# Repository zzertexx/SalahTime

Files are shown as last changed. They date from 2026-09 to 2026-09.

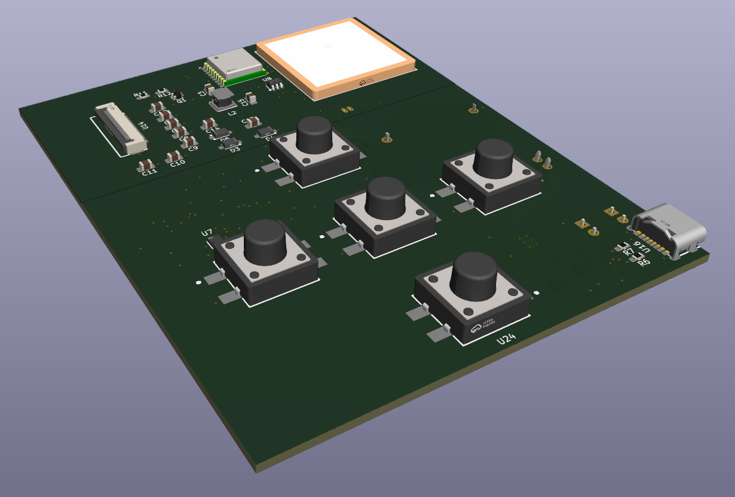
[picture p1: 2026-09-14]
Images/PCB_Front.png

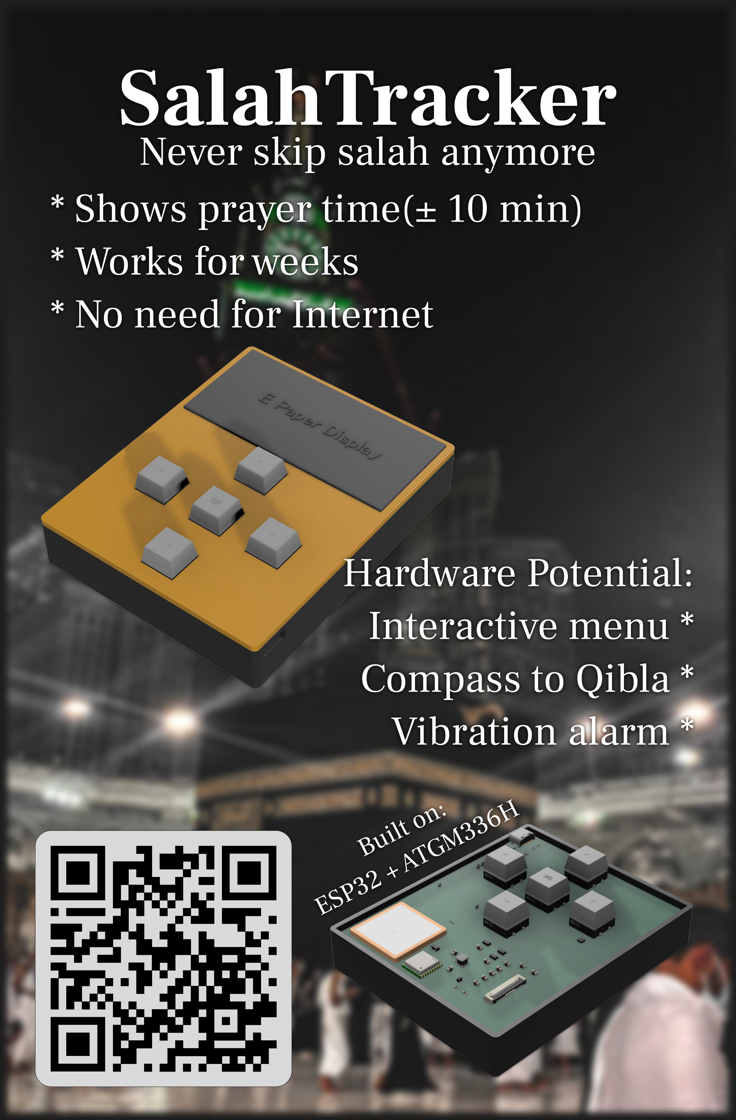
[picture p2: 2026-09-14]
Zine.png

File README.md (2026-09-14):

# SalahTime
Device that shows prayer time and Qibla direction anywhere & anytime without any internet connection
Zine

## What is it?
It is an ESP32-powered device with buttons, GNSS receiver, RTC, magnetic sensor, and E-Paper display. By using all of these, it is planned to show prayer time using latitude and longitude alongside with direction to Qibla by magnetic sensor. Because there is an E-Paper display, battery can last for many-many days. If the battery will be drained, it is easy to charge using universal Type-C port. Currently, it shows prayer time based on location, but will have full interface and direction to Qibla in the future.

## Why did I build it?
I was walking in Shenzhen after Fallout with my phone died and then realized that I have to read Salah
I could not know if the next salah already started and I needed the direction to Qibla
Strangers there do not understand English, so I could not communicate with them
Then, I got an idea of internet-free device that can predict prayer time and show the direction to Qibla

## Steps to Reproduce
1. Order PCB and parts from any provider(Example: JLCPCB)
2. Assemble and solder parts to PCB
3. 3D Print CAD models from "CAD" folder
4. Push software into MCU and download required libraries using Arduino IDE 
5. Use!

## Arduino IDE Libraries:
GxEPD2
TinyGPS++
RTClib

## Bill of Materials
| Name | Quantity | Price |
| --- | --- | --- |
| DS3231M RTC | 1 | 3.25$ |
| ATGM336H GNSS | 1 | 2.22$ |
| ESP32-C3FH4 | 1 | 2.18$ |
| Vibration Motor | 1 | 0.56$ |
| Tactile Push Buttons | 5 | 0.3$ |
| Ceramic Active Antenna | 1 | 0.73$ |
| Coin Cell Holder | 1 | 1.27$ |
| MAX17048 fuel gauges | 1 | 2.18$ |
| ME6211 LDO to 3.3v | 1 | 0.52$ |
| NPN Transistor | 1 | 0.02$ |
| 2.9-inch E Ink Display | 1 | 4$ |
| 803040 1000 mAh LiPo | 1 | 4$ |
| Type-C 8 Pin | 1 | 0.04$ |
| 2.5mm JST Connector | 1 | 0.04$ |
| SI1308EDL N-MOSFET | 1 | 0.1$ |
| TP4056 | 1 | 0.2$ |
| FS8205A | 1 | 0.05$ |
| DW01A | 1 | 0.5$ |
| E Ink connector | 1 | 0.11$ |
| QST QMC5883P | 1 | 1.6$ | 
| 0,1uF C | 6 | 0.2$ |
| 10uF | 3 | 0.2$ | 
| 1uF/25V | 14 | 0.7$ |
| 4.7uF/25V | 3 | 0.2$ |
| 15pF | 2 | 0.03$ |
| 10nF | 1 | 0.02$ |
| THT 3mm diodes | 2 | 0.07$ |
| MBR0530 Diode | 3 | 0.02$ |
| 47nH L | 1 | 0,06$ |
| 47uH L | 1 | 0.08$ |
| 2nH L | 1 | 0.01$ |
| 10K R | 1 | 0.01$ |
| 1K R | 4 | 0.01$ |
| 1.2K R | 1 | 0.05$ |
| 4.7K R | 2 | 0.07$ |
| 100 R | 1 | 0.01$ |
| 1M R | 1 | 0.01$ |
| 2.2 R | 1 | 0.01$ |
| 499 R | 1 | 0.01$ |
| 0 R | 1 | 0.01$ |
| 10pF Crystal | 1 | 0.3$ | 
| TOTAL: | 26$ |

## Images
salah_tracker
salah_tracker2
[schematics.pdf](https://github.com/user-attachments/files/32201017/schematics.pdf)
PCB_Front
PCB_Behind

## AI DISCLOSURE
AI was used to search components and to write computing algorithm

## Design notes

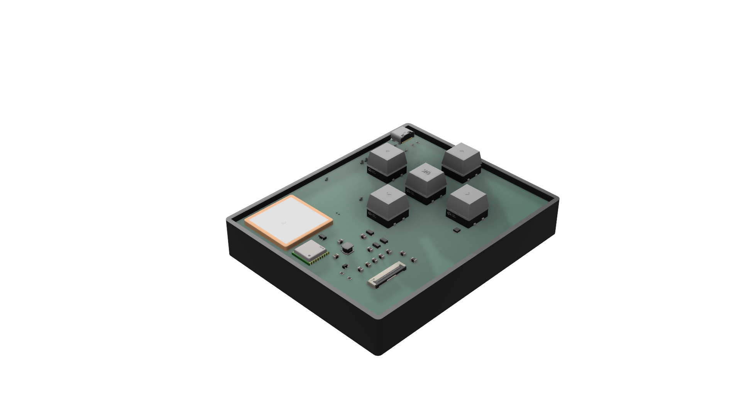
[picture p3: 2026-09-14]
Images/salah_tracker2.png

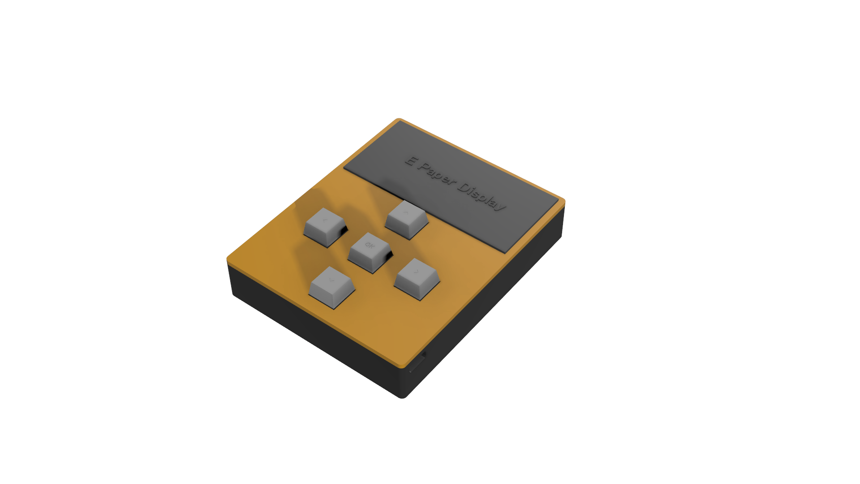
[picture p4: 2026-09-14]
Images/salah_tracker.png

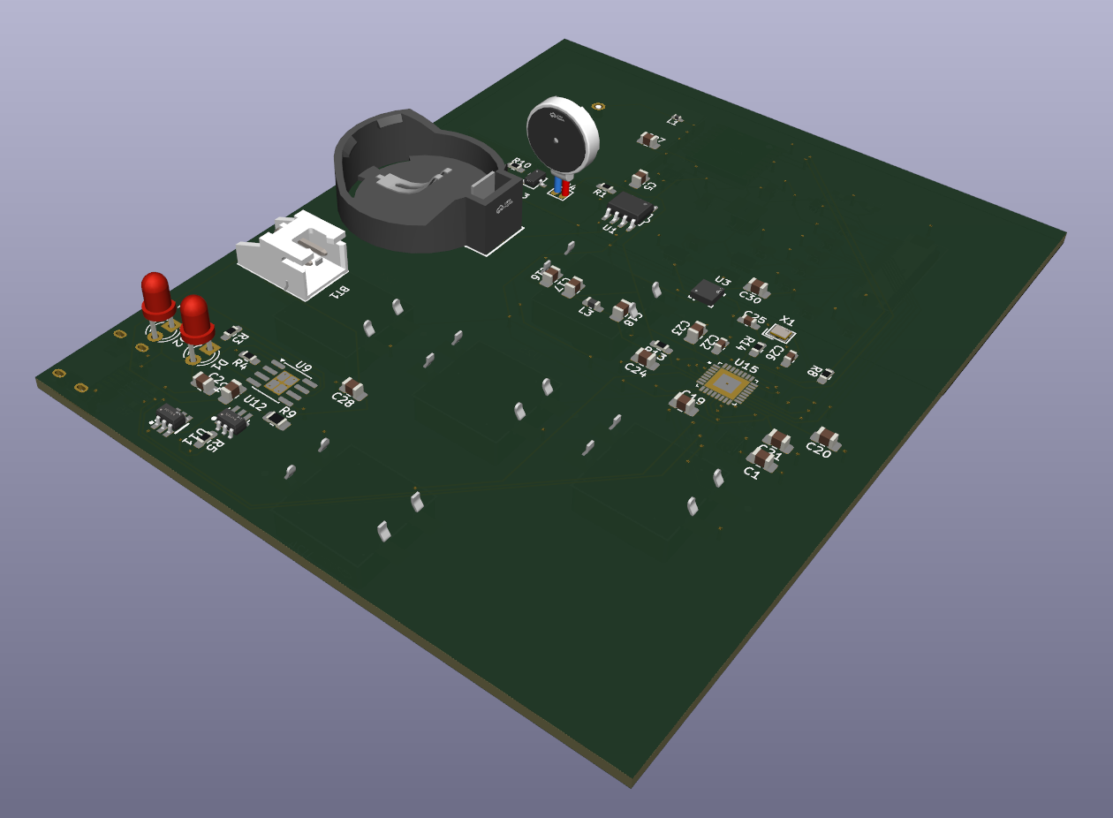
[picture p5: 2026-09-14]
Images/PCB_Behind.png

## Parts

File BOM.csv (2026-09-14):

Name | Quantity | Total Price | LCSC Number | Link
MAXIM DS3231MZ+TRL | 1 | $3,25 | C107410 | https://www.lcsc.com/product-detail/C107410.html?s_z=n_q_%2509DS3231MZ%2520TRL
ZHONGKEWEI ATGM336H-7N76 | 1 | $2,22 | C53325902 | https://www.lcsc.com/product-detail/C53325902.html
ESP32-C3FH4 | 1 | $2,18 | C2858491 | https://www.lcsc.com/product-detail/C2858491.html
Vibration Motor | 1 | $0,56 | C2759984 | https://jlcpcb.com/partdetail/LEADER-LCM1027A2445F/C2759984
Push Switch | 5 | $0,30 | C48677734 | https://www.lcsc.com/product-detail/C48677734.html?s_z=n_q_C48677734&globalKeyword=C48677734
Ceramic Active Antenna | 1 | $0,73 | C784398 | https://www.lcsc.com/product-detail/C784398.html
Coin Cell Holder | 1 | $1,27 | C964745 | https://www.lcsc.com/product-detail/C964745.html
MAX17048 | 1 | $2,18 | C2682616 | https://www.lcsc.com/product-detail/C2682616.html?s_z=n_q_MAX17048%2520
ME6211 | 1 | $0,52 | C82942 | https://www.lcsc.com/product-detail/C82942.html?s_z=n_q_t_ME6211%2520
NPN Transistor | 1 | $0,02 | C52801 | https://www.lcsc.com/product-detail/C52801.html?s_z=n_q_t_NPN%2520
2.9-inch E Ink Display | 1 | $4,00 |  | https://www.alibaba.com/product-detail/2-9inch-2-9-E-Ink_1601697951336.html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
803040 1000 mAh LiPo | 1 | $4,00 |  | https://aliexpress.ru/item/1005008542711399.html?sku_id=12000045637966057
Type-C 8 Pin | 1 | $0,04 | C47326496 | https://www.lcsc.com/product-detail/C47326496.html
2.5mm JST Connector | 1 | $0,04 | C158012 | https://www.lcsc.com/product-detail/C158012.html?s_z=n_q_t_2.5%2520mm%25202%2520pin
SI1308EDL | 1 | $0,10 | C7603347 | https://www.lcsc.com/product-detail/C7603347.html?s_z=n_q_Si1308EDL
TP4056 | 1 | $0,20 | C16581 | https://www.lcsc.com/product-detail/C16581.html?s_z=n_q_TP4056
FS8205A | 1 | $0,05 | C2830320 | https://www.lcsc.com/product-detail/C2830320.html?s_z=s_p_FS8205A
DW01A | 1 | $0,50 | C351410 | https://www.lcsc.com/product-detail/C351410.html?s_z=n_q_DW01A
BC817-40,215 | 1 | $0,01 | C52801 | https://www.lcsc.com/product-detail/C52801.html?s_z=n_q_C52801&globalKeyword=C52801
E Ink connector | 1 | $0,11 | C2856805 | https://www.lcsc.com/product-detail/C2856805.html?s_z=n_q_C2856805&globalKeyword=C2856805
QST QMC5883P | 1 | $1,57 | C2847467 | https://www.lcsc.com/product-detail/C2847467.html
Capacitors:
0,1uF | 6 | $0,20 | C49678 | https://www.lcsc.com/product-detail/C49678.html?s_z=n_q_t_capacitor
10uF | 3 | $0,20 | C15850 | https://www.lcsc.com/product-detail/C15850.html?s_z=n_q_t_capacitor
1uF/25V | 14 | $0,70 | C116352 | https://www.lcsc.com/product-detail/C116352.html?s_z=n_q_t_capacitor
4.7uF/25V | 3 | $0,20 | C98195 | https://www.lcsc.com/product-detail/C98195.html?s_z=n_q_t_capacitor
15pF | 2 | $0,03 | C1644 | https://www.lcsc.com/product-detail/C1644.html
10nF | 1 | $0,02 | C100042 | https://www.lcsc.com/product-detail/C100042.html
Diodes:
THT Red LED Diode 3mm | 2 | $0,07 | C99772 | https://www.lcsc.com/product-detail/C99772.html
MBR0530 | 3 | $0,02 | C5204746 | https://www.lcsc.com/product-detail/C5204746.html?s_z=n_q_MBR0530
Inductors:
47nH | 1 | $0,06 | C54534559 | https://www.lcsc.com/product-detail/C54534559.html?s_z=n_q_t_Inductor
47uH | 1 | $0,08 | C167888 | https://www.lcsc.com/product-detail/C167888.html?s_z=n_q_NR3015
2nH | 1 | $0,00 | C55067196 | https://www.lcsc.com/product-detail/C55067196.html?s_z=s_c_Fixed%2520Inductors
Resistors:
10K Pull Up | 1 | $0,01 | C98220 | https://www.lcsc.com/product-detail/C98220.html
1K | 4 | $0,01 | C2907002 | https://www.lcsc.com/product-detail/C2907002.html
1.2K | 1 | $0,05 | C2907002 | https://www.lcsc.com/product-detail/C269531.html
4.7K | 2 | $0,07 | C2904521 | https://www.lcsc.com/product-detail/C2904521.html
100 | 1 | $0,01 | C2907218 | https://www.lcsc.com/product-detail/C2907218.html
1M | 1 | $0,01 | C2907003 | https://www.lcsc.com/product-detail/C2907003.html
2.2 | 1 | $0,01 | C22939 | https://www.lcsc.com/product-detail/C22939.html
499 | 1 | $0,00 | C23065 | https://www.lcsc.com/product-detail/C23065.html
0 | 1 | $0,00 | C95177 | https://www.lcsc.com/product-detail/C95177.html
Crystal | 1 | $0,30 | C255898 | https://www.lcsc.com/product-detail/C255898.html

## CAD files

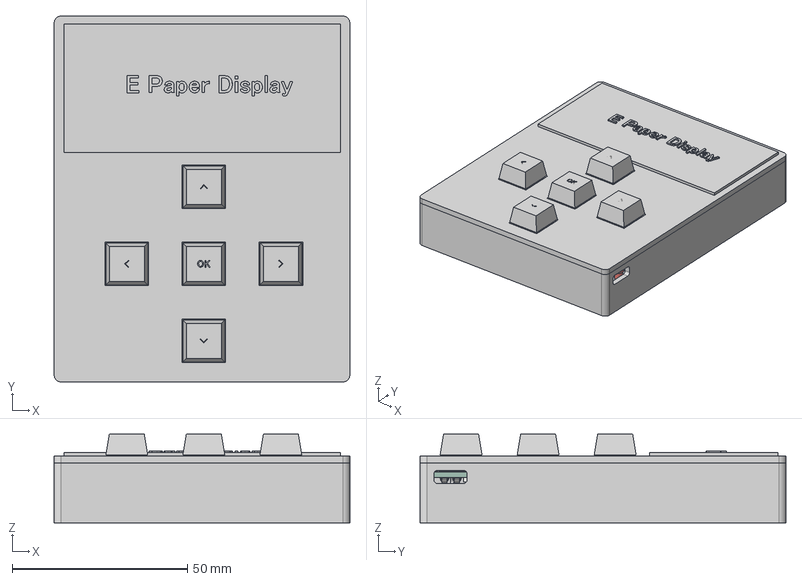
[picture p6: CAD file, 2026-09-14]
CAD/case.step
84.5 x 104.5 x 25.3 mm
cap for 12x12 (1)

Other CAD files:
CAD/case.f3z

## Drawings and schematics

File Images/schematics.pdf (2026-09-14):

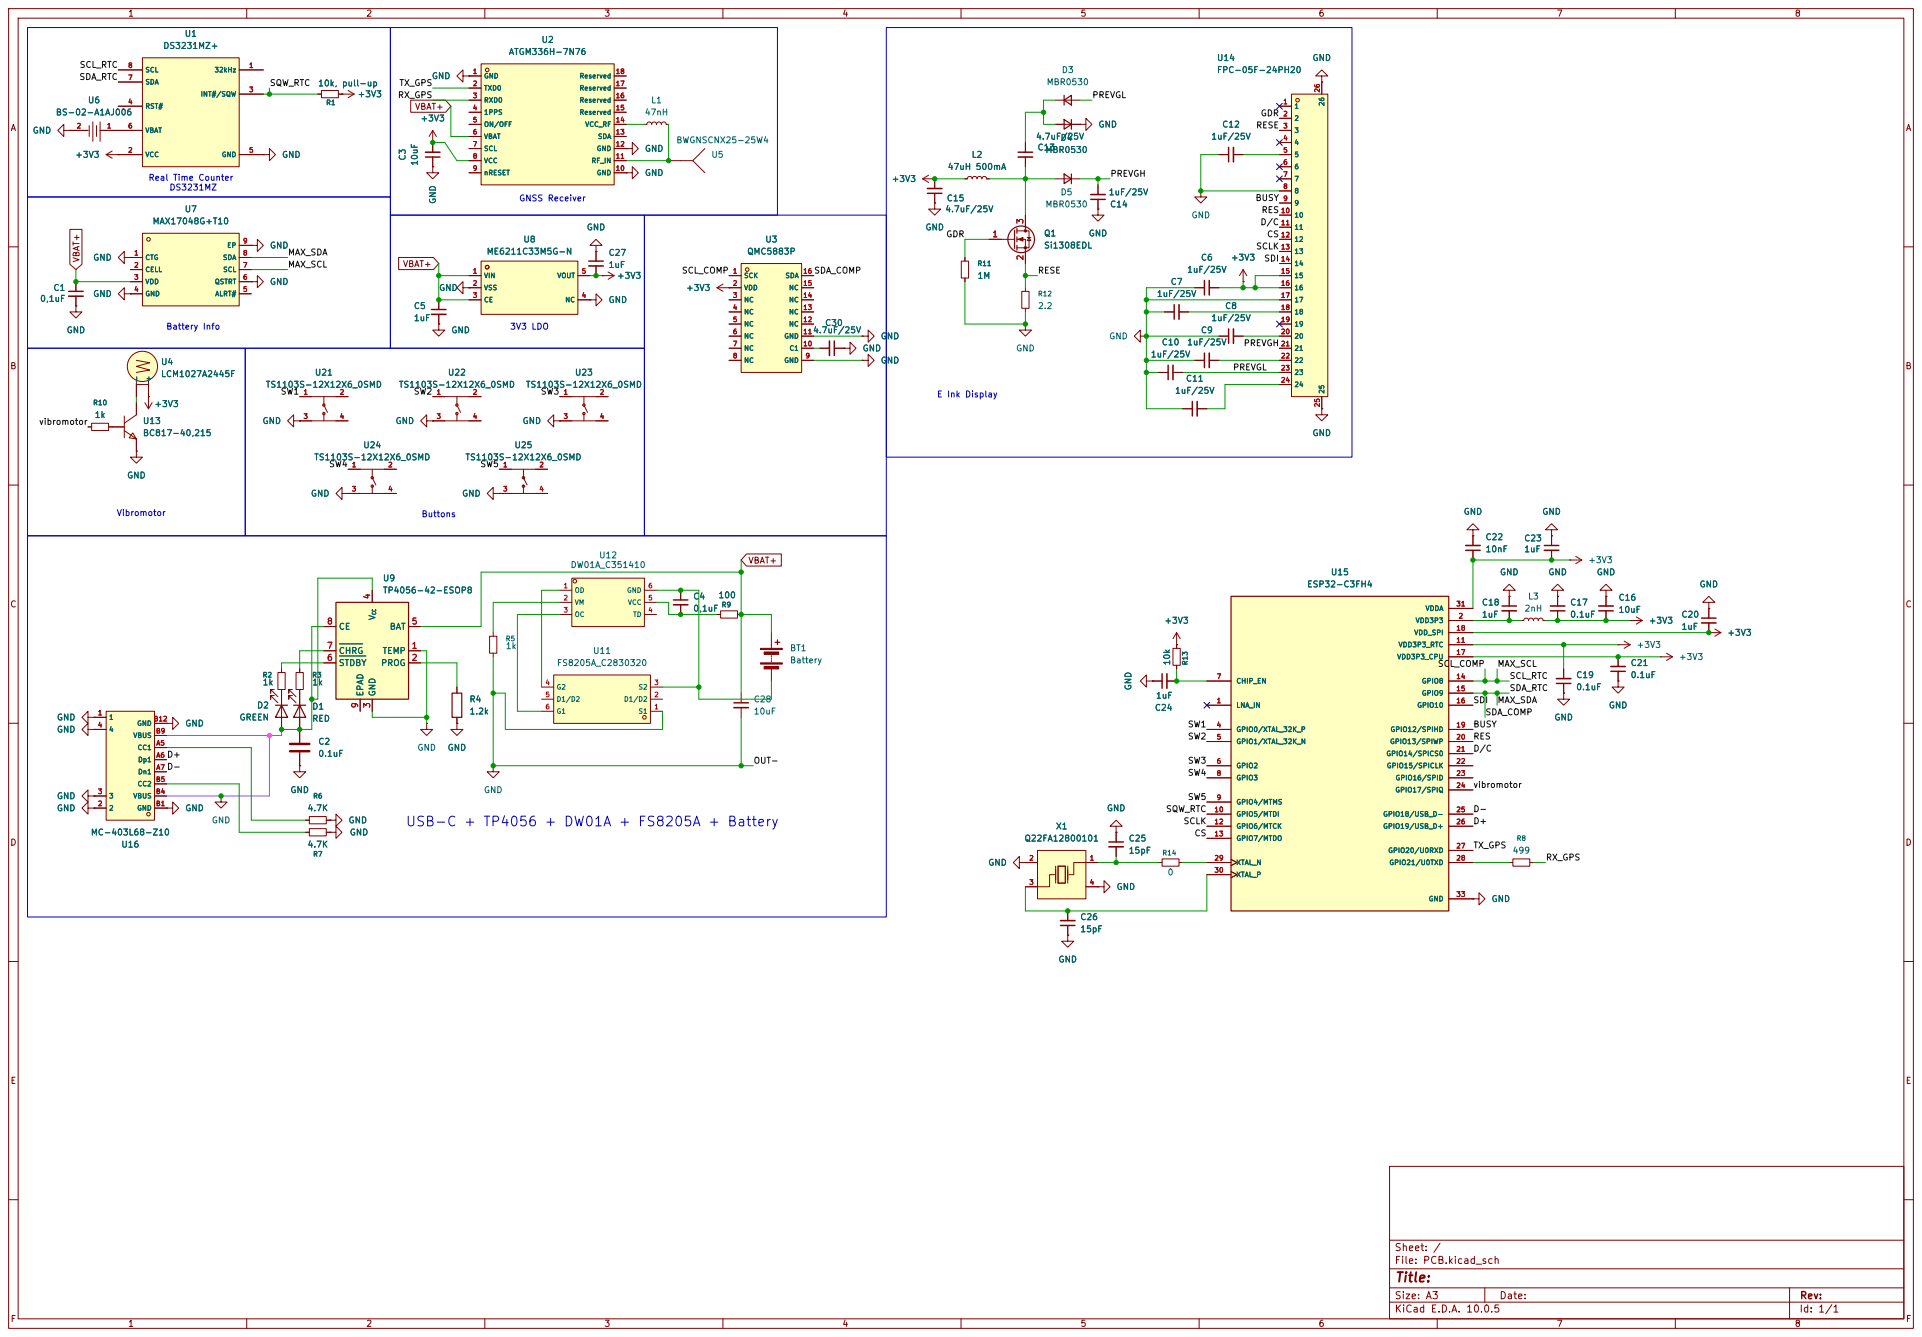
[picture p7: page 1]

GND | SDA | 16 U3 QMC5883P GND

VibromotorBattery Info LCM1027A2445F +3V3 LCM1027A2445F - | 3 4 U21 3 4 U21 3 4 U22 3 4 GND 3 U23 4 U23 TS1103S-12X12X6_0SMD TS1103S-12X12X6_0SMD TS1103S-12X12X6_0SMD TS1103S-12X12X6_0SMD TS1103S-12X12X6_0SMD TS1103S-12X12X6_0SMD 1 1 2 2 1 1 2 2 SW3 1 1 2 2 GND 3 4 GND U25 3 4 GND 3 4 U24 3 4 U25 TS1103S-12X12X6_0SMD TS1103S-12X12X6_0SMD TS1103S-12X12X6_0SMD TS1103S-12X12X6_0SMD SW4 1 1 2 2 SW5 1 1 2 2

Size: A3 | Rev: | F Date:
KiCad E.D.A. 10.0.5 | Id: 1/1

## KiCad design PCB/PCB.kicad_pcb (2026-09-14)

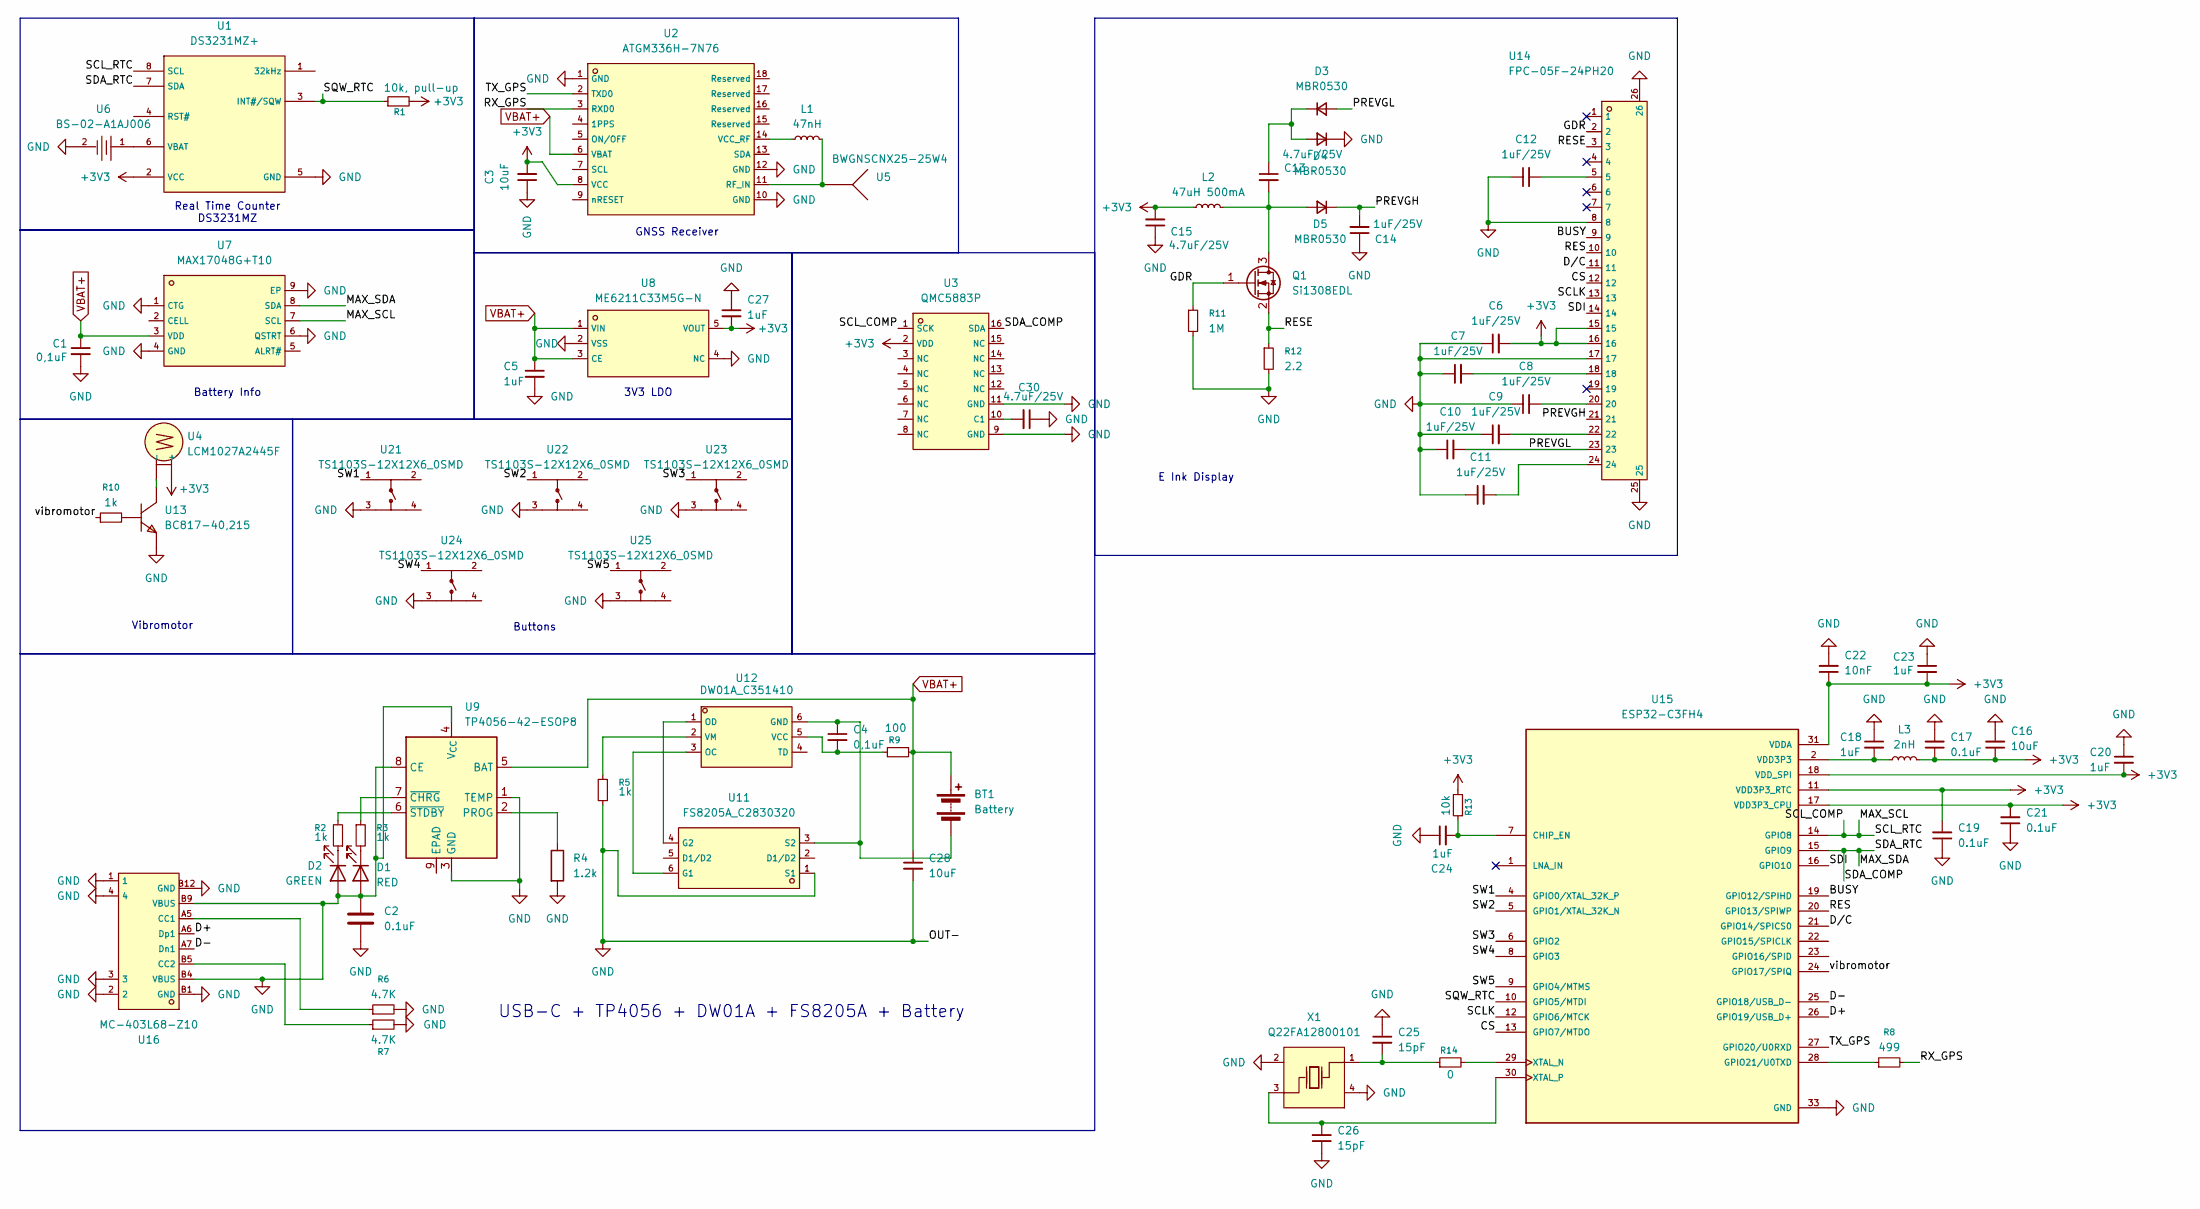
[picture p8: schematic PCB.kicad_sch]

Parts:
BT1: Battery; CONN-TH_S2B-XH-A-LF-SN
C1, C4: 0,1uF; C_0805_2012Metric_Pad1.18x1.45mm_HandSolder
C2, C17, C19, C21: 0.1uF; C_0805_2012Metric_Pad1.18x1.45mm_HandSolder
C3, C16, C28: 10uF; C_0805_2012Metric_Pad1.18x1.45mm_HandSolder
C5, C18, C20, C23, C24, C27: 1uF; C_0805_2012Metric_Pad1.18x1.45mm_HandSolder
C6, C7, C8, C9, C10, C11, C12, C14: 1uF/25V; C_0805_2012Metric_Pad1.18x1.45mm_HandSolder
C13, C15, C30: 4.7uF/25V; C_0805_2012Metric_Pad1.18x1.45mm_HandSolder
C22: 10nF; C_0603_1608Metric_Pad1.08x0.95mm_HandSolder
C25, C26: 15pF; C_0603_1608Metric_Pad1.08x0.95mm_HandSolder
D1: RED; LED_D3.0mm
D2: GREEN; LED_D3.0mm
D3, D4, D5: MBR0530; SOD-123_L2.7-W1.6-LS3.7-RD-1
L1: 47nH; L_0402_1005Metric_Pad0.77x0.64mm_HandSolder
L2: 47uH 500mA; IND-SMD_L4.0-W4.0_FNR40XXS
L3: 2nH; L_0603_1608Metric_Pad1.05x0.95mm_HandSolder
Q1: Si1308EDL; SOT-323_SC-70
R1: 10k, pull-up; R_0603_1608Metric_Pad0.98x0.95mm_HandSolder
R2, R3, R5, R10: 1k; R_0603_1608Metric_Pad0.98x0.95mm_HandSolder
R4: 1.2k; R_0603_1608Metric_Pad0.98x0.95mm_HandSolder
R6, R7: 4.7K; R_0603_1608Metric_Pad0.98x0.95mm_HandSolder
R8: 499; R_0603_1608Metric_Pad0.98x0.95mm_HandSolder
R9: 100; R_0805_2012Metric_Pad1.20x1.40mm_HandSolder
R11: 1M; R_0603_1608Metric_Pad0.98x0.95mm_HandSolder
R12: 2.2; R_0603_1608Metric_Pad0.98x0.95mm_HandSolder
R13: 10k; R_0603_1608Metric_Pad0.98x0.95mm_HandSolder
R14: 0; R_0603_1608Metric_Pad0.98x0.95mm_HandSolder
U1: DS3231MZ+; SOIC-8_L4.9-W3.9-P1.27-LS6.0-BL; LCSC C107410
U2: ATGM336H-7N76; COMM-SMD_18P-L10.1-W9.7-P1.1-TL_L76-LB; LCSC C53325902
U3: QMC5883P; LGA-16_L3.0-W3.0-P0.50-BL_SQ; LCSC C2847467
U4: LCM1027A2445F; VIBRATING-MOTOR-SMD_WELDING; LCSC C2759984
U5: BWGNSCNX25-25W4; ANT-TH_L25.0-W25.0; LCSC C784398
U6: BS-02-A1AJ006; BAT-TH_MYOUNG_BS-02-A1AJ006; LCSC C964745
U7: MAX17048G+T10; TDFN-8_L2.0-W2.0-P0.50-BL-EP1.2; LCSC C2682616
U8: ME6211C33M5G-N; SOT-23-5_L3.0-W1.7-P0.95-LS2.8-BL; LCSC C82942
U9: TP4056-42-ESOP8; SOIC-8-1EP_3.9x4.9mm_P1.27mm_EP2.41x3.3mm_ThermalVias
U11: FS8205A_C2830320; SOT-23-6_L2.9-W1.6-P0.95-LS2.8-BR; LCSC C2830320
U12: DW01A_C351410; SOT-23-6_L2.9-W1.6-P0.95-LS2.8-BL; LCSC C351410
U13: BC817-40,215; SOT-23-3_L2.9-W1.6-P1.90-LS2.8-BR; LCSC C52801
U14: FPC-05F-24PH20; FPC-SMD_24P-P0.50_FPC-05F-24PH20; LCSC C2856805
U15: ESP32-C3FH4; QFN50P500X500X90-33N; PARTREV 2.0
U16: MC-403L68-Z10; USB-TYPE-C-SMD_MC-403L68-Z10; LCSC C47326496
U21, U22, U23, U24, U25: TS1103S-12X12X6_0SMD; SW-SMD_4P-L12.0-W12.0-P5.00-LS15.5; LCSC C48677734
X1: Q22FA12800101; CRYSTAL-SMD_4P-L2.0-W1.6-BL; LCSC C255898

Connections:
+3V3: C3.2, C6.2, C15.2, C16.1, C17.1, C19.2, C20.2, C21.2, C22.1, C23.2, C27.2, L2.1, L3.2, R1.2, R13.2, U1.2 (VCC), U2.8 (VCC), U3.2 (VDD), U4.2 (+), U8.5 (VOUT), U14.15, U14.16, U15.11 (VDD3P3_RTC), U15.17 (VDD3P3_CPU), U15.18 (VDD_SPI), U15.31 (VDDA), U15.32 (VDDA)
/BUSY: U14.9, U15.19 (GPIO12/SPIHD)
/CS: U14.12, U15.13 (GPIO7/MTDO)
/D+: U15.26 (GPIO19/USB_D+), U16.A6 (Dp1)
/D-: U15.25 (GPIO18/USB_D-), U16.A7 (Dn1)
/D/C: U14.11, U15.21 (GPIO14/SPICS0)
/GDR: Q1.1 (G), R11.1, U14.2
/MAX_SCL: U1.8 (SCL), U3.1 (SCK), U7.7 (SCL), U15.14 (GPIO8)
/MAX_SDA: U1.7 (SDA), U3.16 (SDA), U7.8 (SDA), U15.15 (GPIO9)
/PREVGH: C14.2, D5.1 (K), U14.21
/PREVGL: C10.2, D3.2 (A), U14.23
/RES: U14.10, U15.20 (GPIO13/SPIWP)
/RESE: Q1.2 (S), R12.1, U14.3
/RX_GPS: R8.2, U2.3 (RXD0)
/SCLK: U14.13, U15.12 (GPIO6/MTCK)
/SDI: U14.14, U15.16 (GPIO10)
/SQW_RTC: R1.1, U1.3 (INT#/SQW), U15.10 (GPIO5/MTDI)
/SW1: U15.4 (GPIO0/XTAL_32K_P), U21.1
/SW2: U15.5 (GPIO1/XTAL_32K_N), U22.1
/SW3: U15.6 (GPIO2), U23.1
/SW4: U15.8 (GPIO3), U24.1
/SW5: U15.9 (GPIO4/MTMS), U25.1
/TX_GPS: U2.2 (TXD0), U15.27 (GPIO20/U0RXD)
/vibromotor: R10.1, U15.24 (GPIO17/SPIQ)
GND: C1.2, C2.1, C2.2, C3.1, C5.2, C6.1, C7.1, C8.1, C9.1, C10.1, C11.1, C12.1, C14.1, C15.1, C16.2, C17.2, C18.1, C19.1, C20.1, C21.1, C22.2, C23.1, C24.1, C25.1, C26.1, C27.1, C28.2, C30.1, D1.2 (A), D2.2 (A), D4.1 (K), R4.2, R5.2, R6.2, R7.2, R11.2, R12.2, U1.5 (GND), U2.1 (GND), U2.10 (GND), U2.12 (GND), U3.9 (GND), U3.11 (GND), U6.2, U7.1 (CTG), U7.4 (GND), U7.6 (QSTRT), U7.9 (EP), U8.2 (VSS), U8.4 (NC), U9.1 (TEMP), U9.3 (GND), U9.4 (V_{CC}), U9.8 (CE), U11.1 (S1), U13.2, U14.8, U14.17, U14.25, U14.26, U15.33 (GND), U16.1, U16.2, U16.3, U16.4, U16.B1 (GND), U16.B4 (VBUS), U16.B9 (VBUS), U16.B12 (GND), U21.3, U22.3, U23.3, U24.3, U25.3, X1.2, X1.4
unnamed: BT1.2 (-), C4.1, U11.3 (S2), U12.6 (GND)
unnamed: C7.2, U14.18
unnamed: C8.2, U14.20
unnamed: C9.2, U14.22
unnamed: C11.2, U14.24
unnamed: C12.2, U14.5
unnamed: D1.1 (K), R3.2
unnamed: D2.1 (K), R2.1
unnamed: C13.1, D3.1 (K), D4.2 (A)
unnamed: C13.2, D5.2 (A), L2.2, Q1.3 (D)
unnamed: R10.2, U13.1
unnamed: U1.6 (VBAT), U6.1
unnamed: L1.2, U2.11 (RF_IN), U5.1 (ANT_1)
unnamed: L1.1, U2.14 (VCC_RF)
unnamed: C30.2, U3.10 (C1)
unnamed: U4.1 (-), U13.3
unnamed: R4.1, U9.2 (PROG)
unnamed: R3.1, U9.7 (~CHRG)
unnamed: R2.2, U9.6 (~STDBY)
unnamed: U11.6 (G1), U12.3 (OC)
unnamed: U11.4 (G2), U12.1 (OD)
unnamed: C4.2, R9.1, U12.5 (VCC)
unnamed: R5.1, U12.2 (VM)
unnamed: C24.2, R13.1, U15.7 (CHIP_EN)
unnamed: R8.1, U15.28 (GPIO21/U0TXD)
unnamed: R14.2, U15.29 (XTAL_N)
unnamed: C26.2, U15.30 (XTAL_P), X1.3 (OSC2)
unnamed: R6.1, U16.A5 (CC1)
unnamed: R7.1, U16.B5 (CC2)
unnamed: C25.2, R14.1, X1.1 (OSC1)
VBAT+: BT1.1 (+), C1.1, C5.1, C28.1, R9.2, U2.6 (VBAT), U7.3 (VDD), U8.1 (VIN), U8.3 (CE), U9.5 (BAT)
VDD3P3: C18.2, L3.1, U15.2 (VDD3P3), U15.3 (VDD3P3)

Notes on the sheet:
3V3 LDO
Battery Info
Buttons
GNSS Receiver
Real Time Counter DS3231MZ
USB-C + TP4056 + DW01A + FS8205A + Battery
E Ink Display
Vibromotor

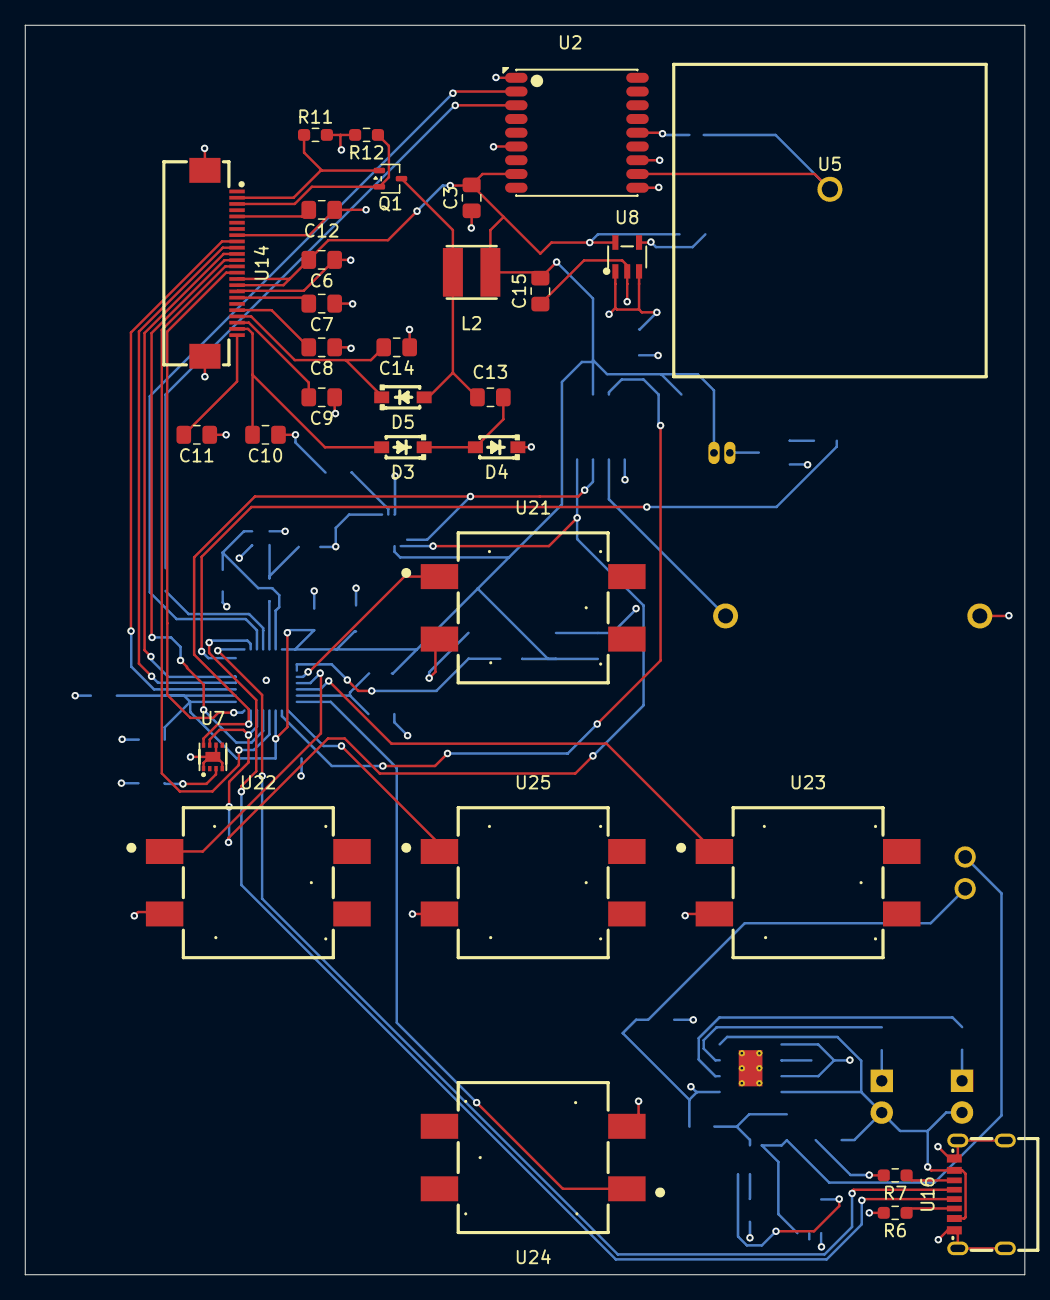
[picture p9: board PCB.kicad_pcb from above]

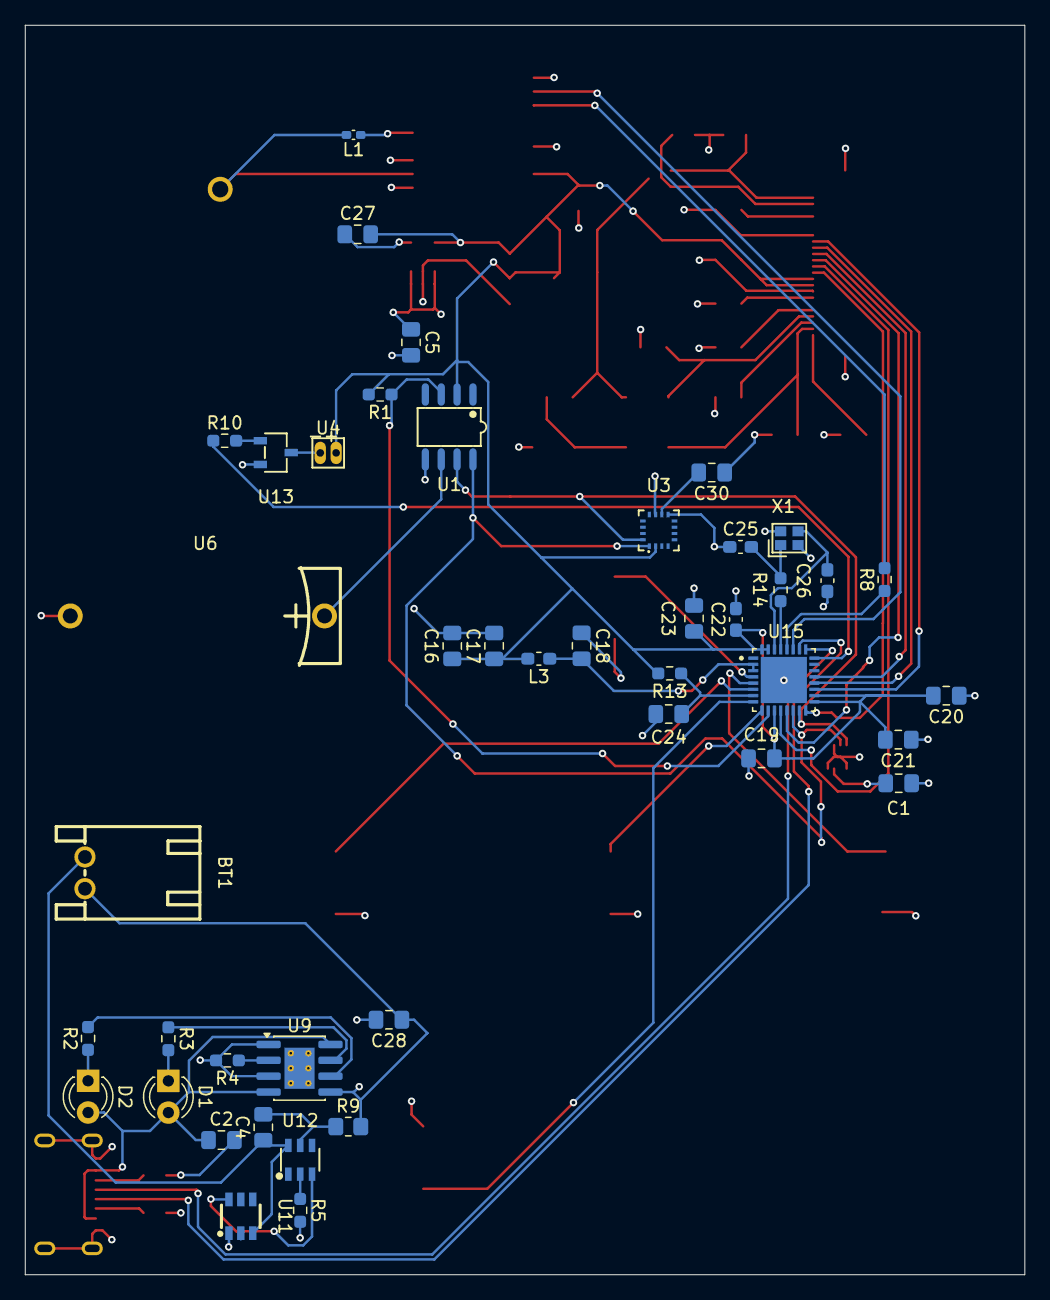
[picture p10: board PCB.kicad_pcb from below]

Board: 4 copper layers, 80.0 x 100.0 mm, 74 parts (43 on the bottom side), 57 nets.

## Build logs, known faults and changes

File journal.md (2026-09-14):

title: "SalahTracker"  
author: "Alimzhan"  
description: "Device that shows prayer time and Qibla direction anywhere & anytime without internet connection!"  
created_at: "2026-09-14"  
---

# July 28-30: Finished procrastinating!

Started BOM and schematics in KiCad


https://lapse.hackclub.com/timelapse/JGiq-3EJbBU8
**Total time spent: 5h:43**

# July 30-31: Added E-Paper Display!

Added connector for E-Paper Display and had my first time with it
Worked more on overall schematics
https://lapse.hackclub.com/timelapse/Z4JN8GHjp6x4


**Total time spent: 3h:2**

# July 30-31: Assigned footprints!

Added connector for E-Paper Display and had my first time with it
Worked more on overall schematics
Assigned footprints and started placing them in PCB


https://lapse.hackclub.com/timelapse/_IZEeHEFUHJL
**Total time spent: 6h:34**

# September 6: Here we go again!

Got back to the project
Continued from designing the PCB
https://lapse.hackclub.com/timelapse/gXpD3ubZHmQ7


**Total time spent: 1h:38**

# September 7: 4 layer PCB!

Made 4 layer PCB
Fixed battery management system (almost submitted a bomb) 
https://lapse.hackclub.com/timelapse/id6ci97hulzv


**Total time spent: 1h:26**

# September 8: battery management on PCB!

Placed footprints of battery management parts on PCB
Researched for computing algorithm
Started firmware
https://lapse.hackclub.com/timelapse/llon2fc7wzqt


**Total time spent: 2h:10**

# September 9: Firmware!

Made basic logic and wrote first part of firmware
https://lapse.hackclub.com/timelapse/CpYjCud1JlU3


**Total time spent: 12 min(lapse)**

# September 12: Wokwi!

I bought subscription at Wokwi to try to simulate Display there - could not make it anyway
Broke the battery management again
https://lapse.hackclub.com/timelapse/jnY-4oCmacKa


**Total time spent: 1h:15**

# September 13: Wokwi again, but more intense!

Tried really hard to print Hello World on that damn Display at Wokwi
Got computing algorithm and implemented in firmware
https://lapse.hackclub.com/timelapse/BHt_oOlLots2


**Total time spent: 2h:20**

# September 14: Made it shippable!

Finished firmware
Made 3D Enclosure
Organized repo
Wrote Journal.md

---

**Total time spent: 5h:00**

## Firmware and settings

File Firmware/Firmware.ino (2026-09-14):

#include <Wire.h>
#include <RTClib.h>
#include <TinyGPS++.h>
#include <GxEPD2_BW.h>
#include <Fonts/FreeMonoBold9pt7b.h>
#include <Preferences.h>
#include <math.h>

#define DEG2RAD(d) ((d) * M_PI / 180.0) 
#define RAD2DEG(r) ((r) * 180.0 / M_PI)

#define SW1 4
#define SW2 5
#define SW3 6
#define SW4 8
#define SW5 9
#define SQW_RTC 10  // INT#/SQW on DS3231
#define SCLK 12     // SCLK on E Ink screen connector
#define CS 13       // CS on E Ink screen connector
#define I2C_SCL 14
#define I2C_SDA 15
#define SDI 16         // SDI on E Ink screen
#define BUSY 19        // BUSY on E Ink screen
#define RES 20         // RES on E Ink screen
#define DC 21          // DC on E Ink screen
#define vibromotor 24  // base on transistor
#define TX_GPS 27
#define RX_GPS 28

const double FAJR_ANGLE = 18.0;
const double ISHA_ANGLE = 18.0;
const double ASR_FACTOR = 2;

struct PrayerTimes {
  double fajr, sunrise, dhuhr, asr, maghrib, isha;
};

double julianDay(int year, int month, int day) {
  if(month <= 2) { 
    year -= 1;
    month += 12;
  }
  int A = year / 100;
  int B = 2 - A + (A / 4);
  return floor(365.25 * (year + 4716)) + floor(30.6001 * (month + 1)) + day + B - 1524.5;
}

void sunPosition(double jd, double &declination, double &eqTimeMinutes) {
  double D = jd - 2451545.0;
  double g = fmod(357.529 + 0.98560028 * D, 360.0);
  double q = fmod(280.459 + 0.98564736 * D, 360.0);
  double L = fmod(q + 1.915 * sin(DEG2RAD(g)) + 0.020 * sin(DEG2RAD(2 * g)), 360.0);

  double e = 23.439 - 0.00000036 * D;

  double RA = RAD2DEG(atan2(cos(DEG2RAD(e)) * sin(DEG2RAD(L)), cos(DEG2RAD(L)))) / 15.0;
  RA = fmod(RA, 24.0);
  if (RA < 0) RA += 24.0; 

  declination = RAD2DEG(asin(sin(DEG2RAD(e)) * sin(DEG2RAD(L))));

  double eqTimeHours = (q / 15.0) - RA;

  if(eqTimeHours > 12) eqTimeHours -= 24;
  if(eqTimeHours < -12) eqTimeHours += 24;
  eqTimeMinutes = eqTimeHours * 60.0;
}

double hourAngle(double angle, double latitude, double declination) {
  double lat = DEG2RAD(latitude);
  double decl = DEG2RAD(declination);
  double a = DEG2RAD(angle);

  double cosH = (-sin(a) - sin(lat) * sin(decl)) / (cos(lat) * cos(decl));

  if (cosH > 1.0) cosH = 1.0;
  if (cosH < -1.0) cosH = -1.0;

  return RAD2DEG(acos(cosH)) / 15.0;
}

double asrHourAngle(double factor, double latitude, double declination) {
  double lat = DEG2RAD(latitude);
  double decl = DEG2RAD(declination);

  double a = -atan(1.0 / (factor + tan(fabs(lat - decl))));
  double cosH = (sin(a) - sin(lat) * sin(decl)) / (cos(lat) * cos(decl));

  if (cosH > 1.0) cosH = 1.0;
  if (cosH < -1.0) cosH = -1.0;

  return RAD2DEG(acos(cosH)) / 15.0;
}

PrayerTimes calculatePrayerTimes(int year, int month, int day, double latitude, double longitude, double timeZoneOffsetHours) {
  double jd = julianDay(year, month, day);

  double declination, eqTimeMinutes;
  sunPosition(jd, declination, eqTimeMinutes);
  double eqTimeHours = eqTimeMinutes / 60.0;

  double dhuhr = 12.0 + timeZoneOffsetHours - (longitude / 15.0) - eqTimeHours;

  double sunHA = hourAngle(0.833, latitude, declination);
  double fajrHA = hourAngle(FAJR_ANGLE, latitude, declination);
  double ishaHA = hourAngle(ISHA_ANGLE, latitude, declination);
  double asrHA = asrHourAngle(ASR_FACTOR, latitude, declination);

  PrayerTimes t;
  t.fajr = dhuhr - fajrHA;
  t.sunrise = dhuhr - sunHA;
  t.dhuhr = dhuhr;
  t.asr = dhuhr + asrHA;
  t.maghrib = dhuhr + sunHA;
  t.isha = dhuhr + ishaHA;

  return t;
}

void printTime(double decimalHours, char* buf, size_t bufSize) {
  if (decimalHours < 0) decimalHours += 24;
  if (decimalHours >= 24) decimalHours -= 24;
  int h = (int)decimalHours;
  int m = (int)round((decimalHours - h) * 60);
  if (m == 60) { m = 0; h += 1; }
  snprintf(buf, bufSize, "%02d:%02d", h, m);
}

// Objects
RTC_DS3231 rtc; // create an object "rtc" of type "RTC_DS3231"
TinyGPSPlus gps;
HardwareSerial gpsSerial(1);
Preferences prefs;

GxEPD2_BW<GxEPD2_290_T5, GxEPD2_290_T5::HEIGHT> display(
  GxEPD2_290_T5(CS, DC, RES, BUSY)
);

bool coldStart = false;

void showStatus(const char* msg) {
  display.setFullWindow();
  display.firstPage();
  do {
    display.fillScreen(GxEPD_WHITE);
    display.setCursor(10, 30);
    display.print(msg);
  } while (display.nextPage());
}

void acquireGpsFixBlocking() {
  unsigned long start = millis();
  bool locked = false;

  while(!locked) {
    while(gpsSerial.available() > 0) {
      gps.encode(gpsSerial.read());
    }

    if(gps.location.isValid() && gps.date.isValid() && gps.time.isValid()) {
      locked = true;

      double lat = gps.location.lat();
      double lng = gps.location.lng();

      rtc.adjust(DateTime(gps.date.year(), gps.date.month(), gps.date.day(), 
                          gps.time.hour(), gps.time.minute(), gps.time.second()));

      prefs.putFloat("lat", lat);
      prefs.putFloat("lng", lng);
      prefs.putBool("setup_done", true);

      Serial.printf("GPS Lock: %.6f, %.6f\n", lat, lng);
      showStatus("GPS Locked!");
      delay(1000);
    }

    if(millis() - start > 300000UL) {
      showStatus("No GPS fix. \nCheck sky view");
      delay(3000);
      start = millis();
    }
  }
}

void setup() {
  Serial.begin(115200);

  // Buttons as inputs
  pinMode(SW1, INPUT_PULLUP);
  pinMode(SW2, INPUT_PULLUP);
  pinMode(SW3, INPUT_PULLUP);
  pinMode(SW4, INPUT_PULLUP);
  pinMode(SW5, INPUT_PULLUP);

  // Vibration + short boot buzz
  pinMode(vibromotor, OUTPUT);
  digitalWrite(vibromotor, HIGH);
  delay(150);
  digitalWrite(vibromotor, LOW);

  // Screen on
  display.init(115200);
  display.setRotation(1);
  display.setFont(&FreeMonoBold9pt7b);
  display.setTextColor(GxEPD_BLACK);
  showStatus("Booting...");

  // I2C + RTC
  Wire.begin(I2C_SDA, I2C_SCL);
  pinMode(SQW_RTC, INPUT_PULLUP);

  if(!rtc.begin()) {
    Serial.println("DS3231 is not recognized!");
    showStatus("ERROR: RTC not found");
  }

  // NVS
  prefs.begin("salahtracker", false); // open a non-dependend on power memory inside of ESP32, false = write allowed
  bool setupComplete = prefs.getBool("setup_done", false);

  // Determine cold start
  bool timeInvalid = rtc.lostPower(); // true if the module lost power since the last check
  bool locationInvalid = !setupComplete;

  if(timeInvalid || locationInvalid){
    coldStart = true;
    Serial.println("COLD START - GPS FIX REQUIRED");
    showStatus("First time setup...\nSearching for GPS");
  } else {
    DateTime now = rtc.now();
    Serial.printf("Current RTC time is: %04d-%02d-%02d %02d:%02d\n", 
                    now.year(), now.month(), now.day(), now.hour(), now.minute());
  }

  gpsSerial.begin(9600, SERIAL_8N1, RX_GPS, TX_GPS);

  if(coldStart) {
    acquireGpsFixBlocking();
  }
  
  double tz = 5.0; // UTC +5

  PrayerTimes pt = calculatePrayerTimes(now.year(), now.month(), now.day(), lat, lng, tz);

  char fajrBuf[6], dhuhrBuf[6], asrBuf[6], maghribBuf[6], ishaBuf[6];
  printTime(pt.fajr, fajrBuf, sizeof(fajrBuf));
  printTime(pt.dhuhr, dhuhrBuf, sizeof(dhuhrBuf));
  printTime(pt.asr, asrBuf, sizeof(asrBuf));
  printTime(pt.maghrib, maghribBuf, sizeof(maghribBuf));
  printTime(pt.isha, ishaBuf, sizeof(ishaBuf));

  char buf(128);
  snprintf(buf, sizeof(buf), 
            "Fajr: %s\nDhuhr: %s\nAsr: %s\nMaghrib: %s\nIsha: %s", fajrBuf, dhuhrBuf, asrBuf, maghribBuf, ishaBuf)
  showStatus(buf);
}

void loop() {
  // put your main code here, to run repeatedly:
}
